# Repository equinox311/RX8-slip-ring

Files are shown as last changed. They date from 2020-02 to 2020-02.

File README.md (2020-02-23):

# RX8-slip-ring



This is a 3D printed slip ring for use in place of a clock spring for use with an NRG Short Hub on a Mazda RX-8. This allows an aftermarket wheel's horn button to work without using tradiational janky methods of putting bobby pins and hairclips behind the wheel.

These files are for personal use and will not be licensed to anyone looking to sell or profit on.

Feel free to donate if you like what you see :) 

    

# Materials Needed
- 1x Mazda_Slip_Ring.STL 3D printed, ABS is suggested
- 1x Brass_Ring_Guide.STL 3D Printed, ABS is suggested
- 1x Brass_Ring.STL, machined from brass or copper, brass is suggested OD = 80mm, ID = 64mm (Check out http://realitymachine.us/ for machining quotes)
- 4x 6.5x10mm springs
- 1x wire soldered to the brass ring
- Dielectric grease between the slip ring and wheel hub
- General purpose grease for the ring guide
- Epoxy to attach brass ring to the ring guide

If you would like to have printed parts created for you, please send me a message over at: www.facebook.com/GROMClusters and we can work something out depending on printer useage time and cost.

# Installation
1. Remove the factory clock spring, this should probably already be done.
2. Take Brass_Ring_Guide.STL and put epoxy on the mating surface of Brass_Ring.STL
3. Place Brass_Ring.STL inside the guides, it should be a bit tight and let the epoxy cure
4. Solder some wire to the back of the brass ring, make sure to offset it from where the bottom spring will contact
5. Install Mazda_Slip_Ring.STL in the same location as the old clock spring.
6. Put some general purpose grease around the spring locators and inside and outside of the races
7. Install the springs
8. Install Brass_Ring_Guide.STL by aligning the holes of the ring with the springs, some light sanding may be needed depending on the tolorences of the brass ring. Brass_Ring_Guide.STL should be able to slide in and out of the race with ease
9. Use a small coating of dielectric grease on the contact surface of Brass_Ring.STL to the NRG Short Hub
10. Install the NRG Short Hub
11. Connect the wire to the 12v supply for the horn
12. Install your aftermarket steering wheel and go BEEP, BEEP!

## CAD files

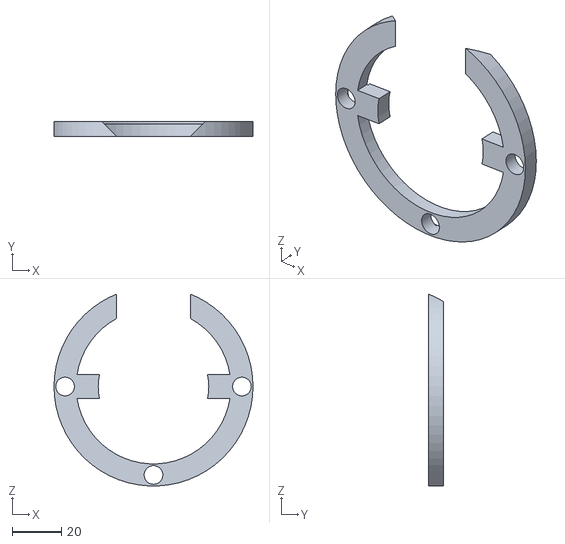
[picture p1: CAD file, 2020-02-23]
Brass_Ring_Guide.STL
81.0 x 6.00 x 78.1

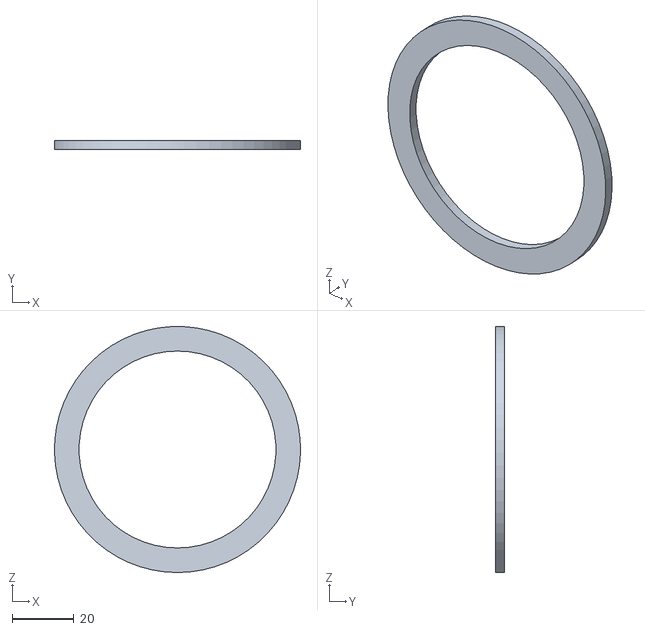
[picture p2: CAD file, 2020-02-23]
Brass_Ring.STL
80.0 x 3.00 x 80.0

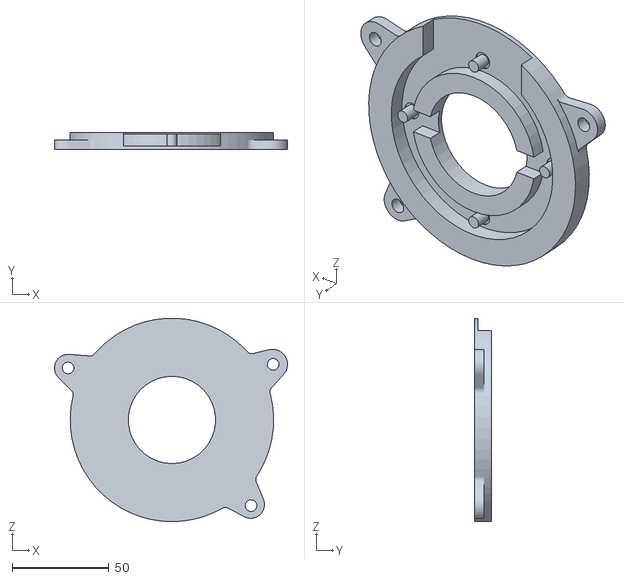
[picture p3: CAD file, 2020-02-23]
Mazda_Slip_Ring.STL
120.2 x 9.00 x 104.9

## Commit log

2020-02-23 Initial Slip ring version
    [Mazda_Slip_Ring.STL]
2020-02-23 Brass Ring
    [Brass_Ring.STL]
2020-02-23 Brass Ring Guide
    NOTE: The inner race needs to be removed, it was deemed to be useless and also has issues slicing properly
    [Brass_Ring_Guide.STL]
